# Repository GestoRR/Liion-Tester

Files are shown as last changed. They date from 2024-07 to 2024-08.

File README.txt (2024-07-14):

v0.x.x - Proof of Concept

For the project, Eagle v9.6.2 software was used.

Creation and implementation of the electrical schematic and PCB design for a Li-ion cell tester.
The tester monitors open-circuit voltage, internal resistance, State of Charge (SoC), Depth of Discharge (DoD), and State of Health (SoH).

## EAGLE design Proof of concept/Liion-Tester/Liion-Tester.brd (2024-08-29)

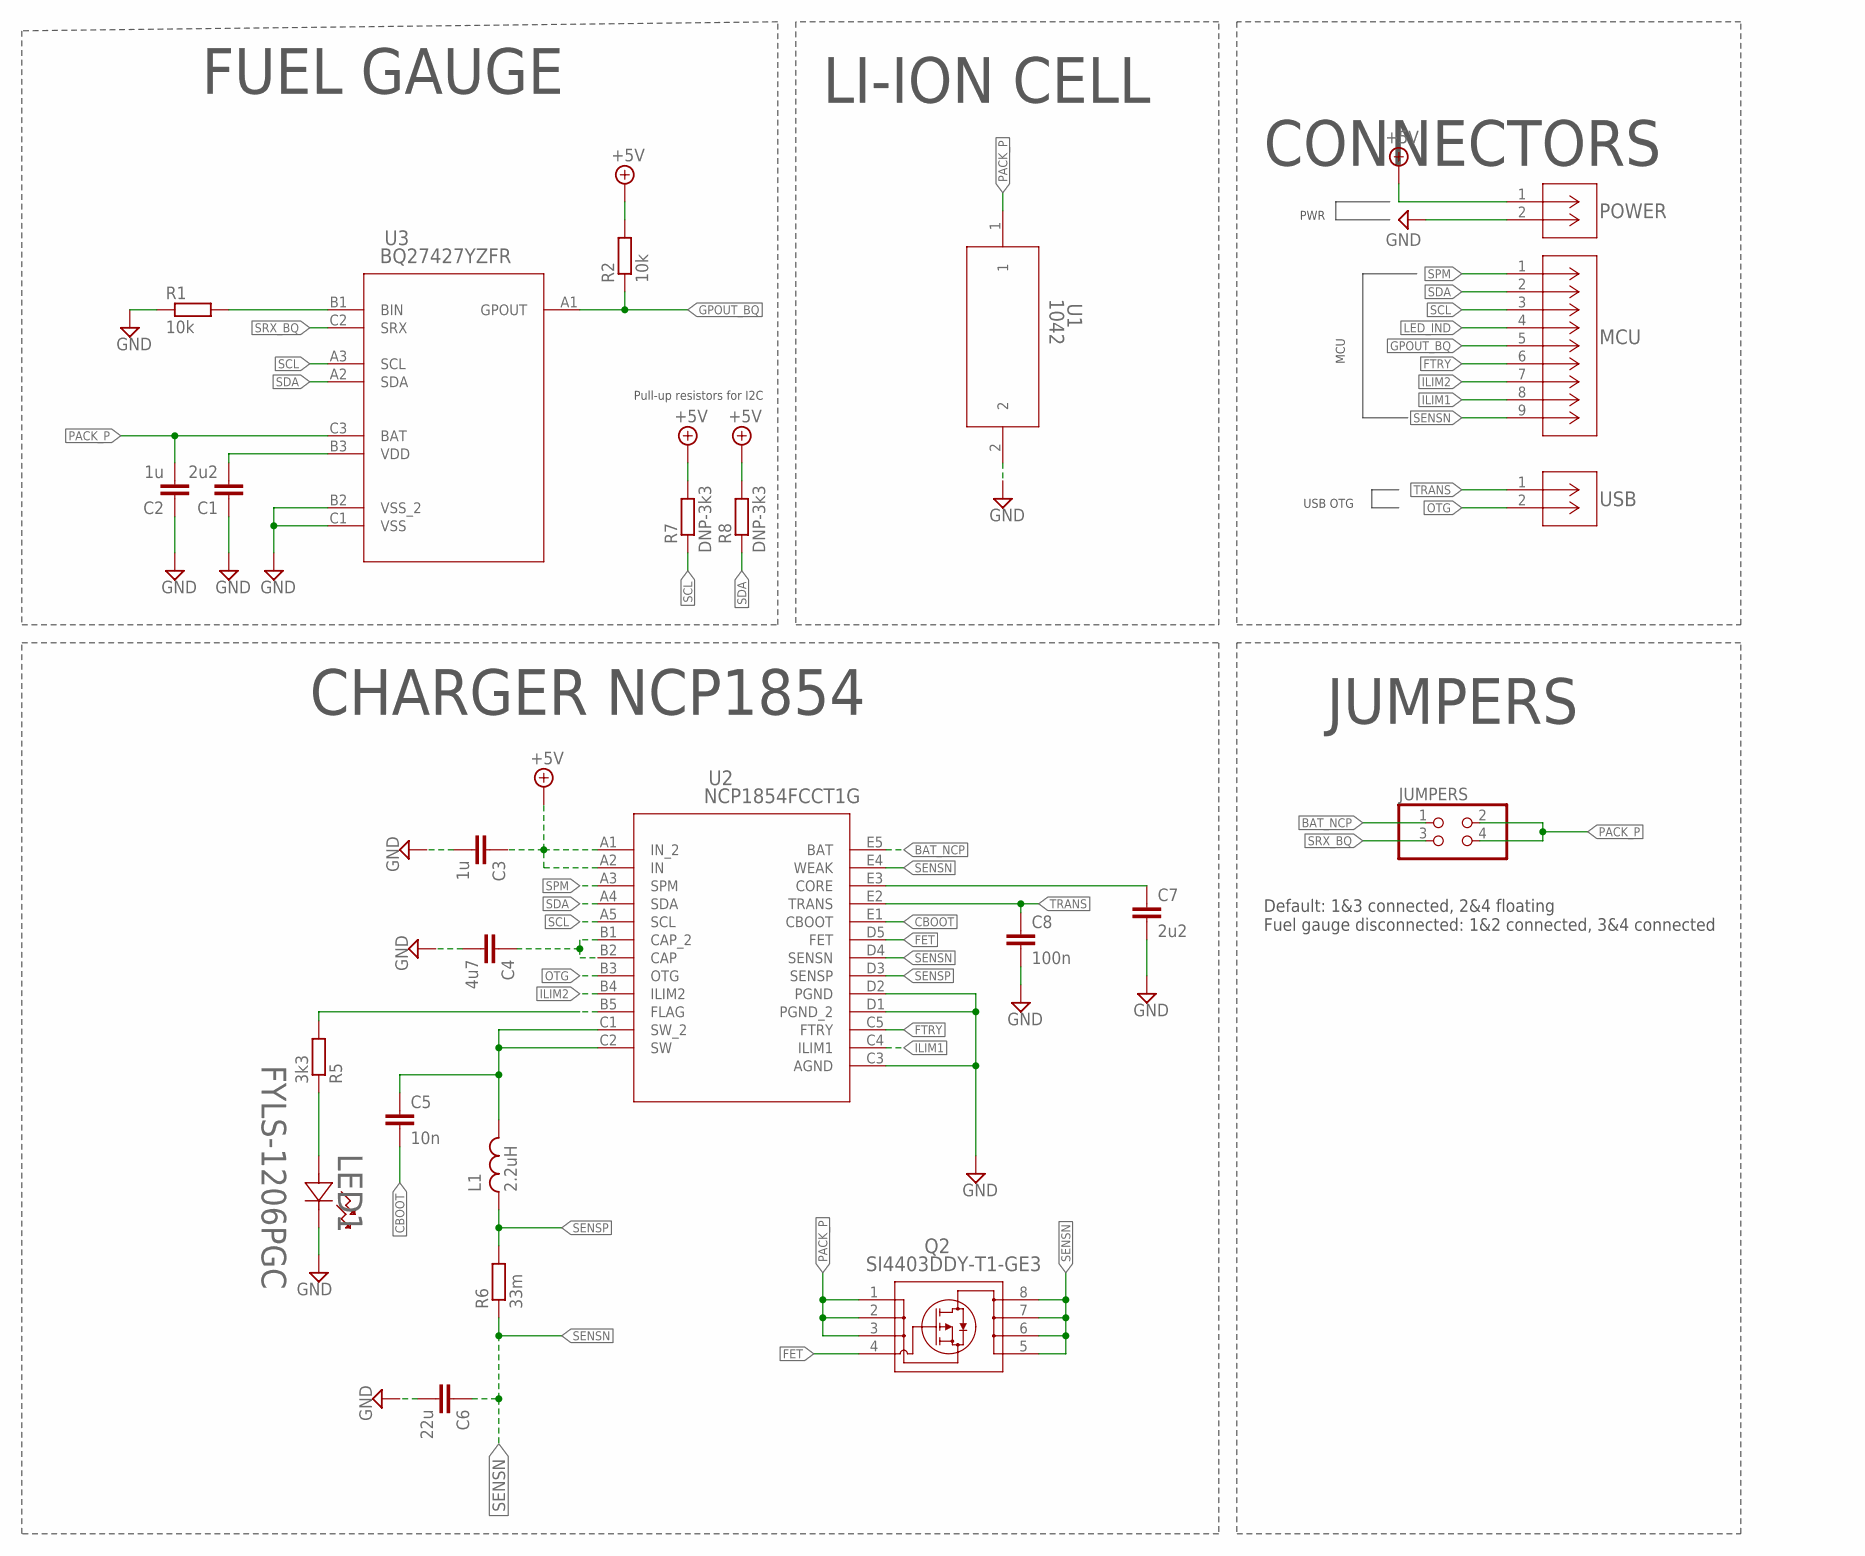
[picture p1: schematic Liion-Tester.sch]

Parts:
C1, C7: 2u2; C0603
C2, C3: 1u; C0603
C4: 4u7; C0603
C5: 10n; C0603
C6: 22u; C0603
C8: 100n; C0603
JUMPERS: PINHD-2X2; 2X02
L1: 2.2uH; SPM3012T-2R2M-LR
LED1: FYLS-1206PGC; LED_QBLP650_1206_QTB
MCU: 250-109; CONN_250-109_WAG
POWER: 250-102; CONN_250-102_WAG
Q2: SI4403DDY-T1-GE3; SO-8_MS-012_VIS
R1, R2: 10k; R0603
R5: 3k3; R0603
R6: 33m; R2512
R7, R8: DNP-3k3; R0603
U1: 1042; 1042_KEY
U2: NCP1854FCCT1G; BGA25_2P55X2P2_ONS
U3: BQ27427YZFR; DSBGA9-YZF_TEX
USB: 250-102; CONN_250-102_WAG

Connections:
+5V: C3.1, POWER.1, R2.2, R7.2, R8.2, U2.A1 (IN_2), U2.A2 (IN)
BAT_NCP: JUMPERS.1, U2.E5 (BAT)
CBOOT: C5.2, U2.E1 (CBOOT)
FET: Q2.4, U2.D5 (FET)
FTRY: MCU.6, U2.C5 (FTRY)
GND: C1.1, C2.1, C3.2, C4.2, C6.2, C7.2, C8.2, LED1.1 (CATHODE), POWER.2, R1.1, U1.2, U2.C3 (AGND), U2.D1 (PGND_2), U2.D2 (PGND), U3.B2 (VSS_2), U3.C1 (VSS)
GPOUT_BQ: MCU.5, R2.1, U3.A1 (GPOUT)
ILIM1: MCU.8, U2.C4 (ILIM1)
ILIM2: MCU.7, U2.B4 (ILIM2)
LED_IND: MCU.4, R5.2, U2.B5 (FLAG)
unnamed: C1.2, U3.B3 (VDD)
unnamed: R1.2, U3.B1 (BIN)
unnamed: C4.1, U2.B1 (CAP_2), U2.B2 (CAP)
unnamed: LED1.2 (ANODE), R5.1
unnamed: C5.1, L1.P$2 (2), U2.C1 (SW_2), U2.C2 (SW)
unnamed: C7.1, U2.E3 (CORE)
OTG: U2.B3 (OTG), USB.2
PACK_P: C2.2, JUMPERS.2, JUMPERS.4, Q2.1, Q2.2, Q2.3, U1.1, U3.C3 (BAT)
SCL: MCU.3, R7.1, U2.A5 (SCL), U3.A3 (SCL)
SDA: MCU.2, R8.1, U2.A4 (SDA), U3.A2 (SDA)
SENSN: C6.1, MCU.9, Q2.5, Q2.6, Q2.7, Q2.8, R6.1, U2.D4 (SENSN), U2.E4 (WEAK)
SENSP: L1.P$1 (1), R6.2, U2.D3 (SENSP)
SPM: MCU.1, U2.A3 (SPM)
SRX_BQ: JUMPERS.3, U3.C2 (SRX)
TRANS: C8.1, U2.E2 (TRANS), USB.1

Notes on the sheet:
FUEL GAUGE
LI-ION CELL
CHARGER NCP1854
Pull-up resistors for I2C
CONNECTORS
USB OTG
MCU
PWR
JUMPERS
Default: 1&3 connected, 2&4 floating Fuel gauge disconnected: 1&2 connected, 3&4 connected

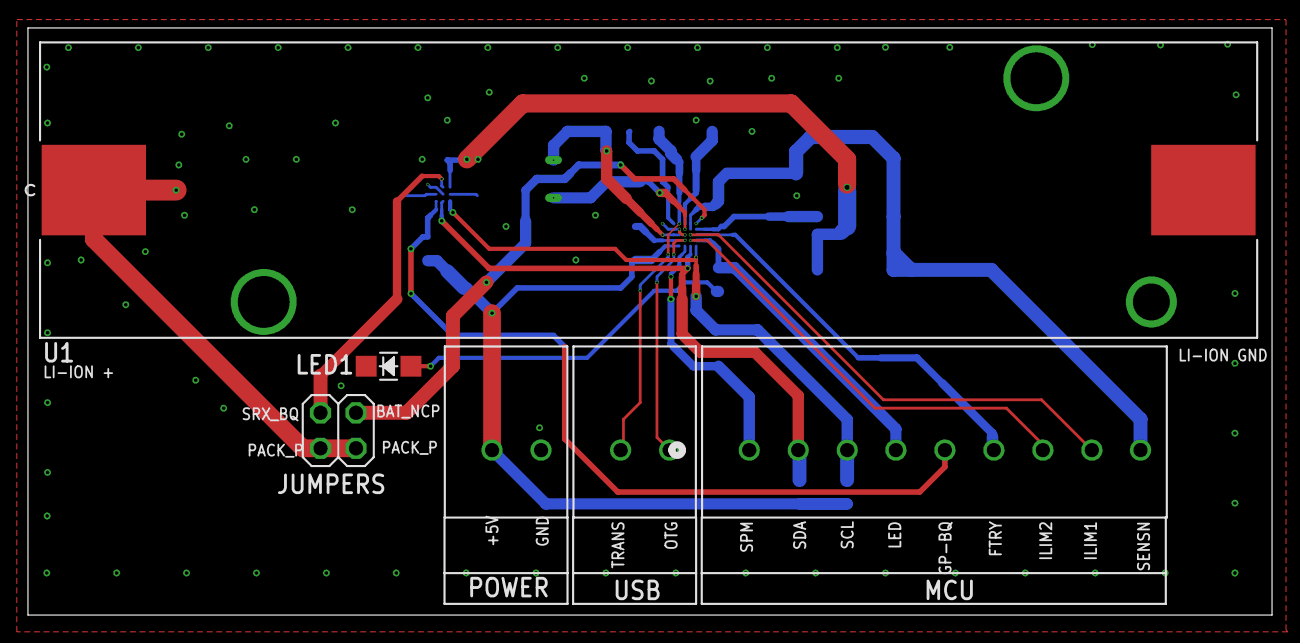
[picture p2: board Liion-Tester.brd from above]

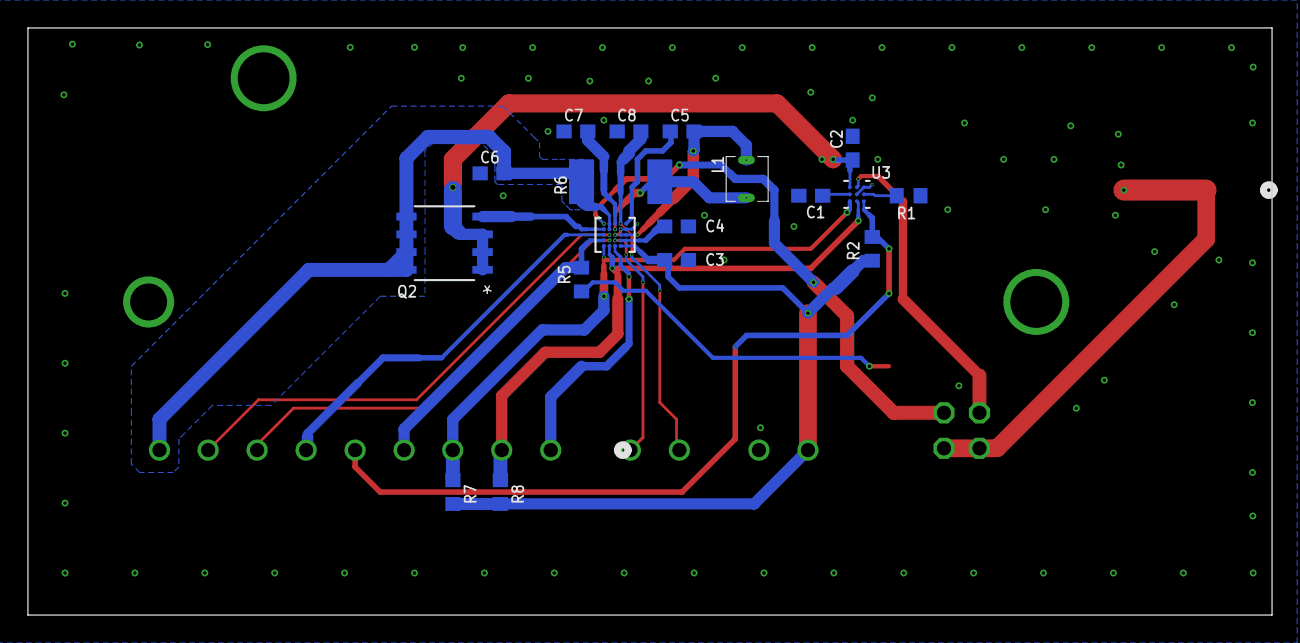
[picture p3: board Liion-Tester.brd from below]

Board: 4 copper layers, 89.0 x 42.0 mm, 24 parts (18 on the bottom side), 25 nets.

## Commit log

2024-07-14 NCP1854 finished connections
    [Liion-Tester.brd, Liion-Tester.sch]
2024-07-16 Rework of BQ and NCP. Connector added to schematic.
    [Liion-Tester.brd, Liion-Tester.sch]
2024-07-22 Final changes in .sch before making .brd
    [Liion-Tester.brd, Liion-Tester.sch]
2024-07-25 Version control
    [Liion-Tester.brd, Liion-Tester.sch]
2024-07-27 Finished .brd with changes in schematic
    [Liion-Tester.brd, Liion-Tester.sch]
2024-08-17 Added polygons for PACK_P and SENS_N
    [Liion-Tester.brd]
2024-08-19 Eliminated one air wire
    [Liion-Tester.brd]
2024-08-29 Bigger vias and 4 layer pcb to order from JLCPCB
    [Liion-Tester.brd]

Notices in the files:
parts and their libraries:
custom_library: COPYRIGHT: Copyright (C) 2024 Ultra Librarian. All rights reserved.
